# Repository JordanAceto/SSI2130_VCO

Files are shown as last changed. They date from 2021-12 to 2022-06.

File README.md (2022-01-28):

# SSI2130 based VCO PCB

## Features:
- Sine, Triangle, Sawtooth, and variable Pulse waves simultaneously available.
- All waveforms +/- 5vpp.
- Three 1 volt/octave inputs
- Through-zero linear FM
- Sync (choose hard or soft)
- PWM modulation inputs (choose triangle or saw input for the pulse wave)
- Designed to plug into a separate carrier pcb which houses the pots and jacks.

## [SCHEMATIC](https://github.com/JordanAceto/SSI2130_VCO/blob/main/construction_docs/SSI2130_VCO_schematic.pdf)

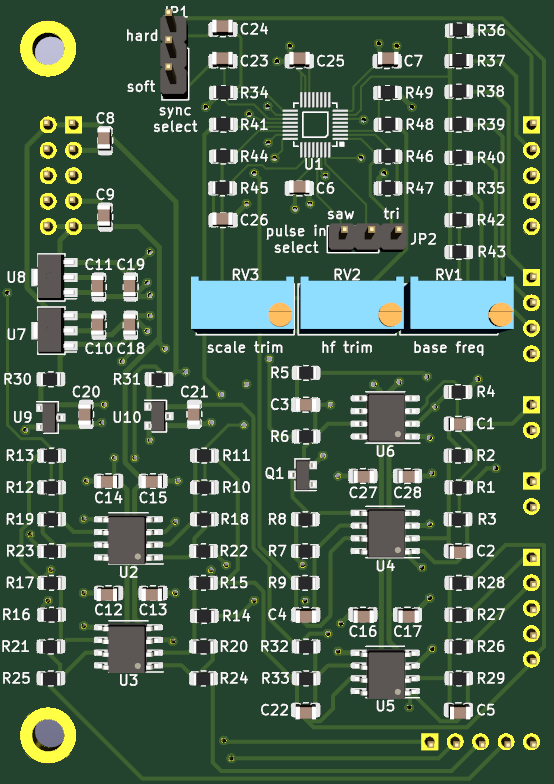
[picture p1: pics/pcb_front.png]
PCB front
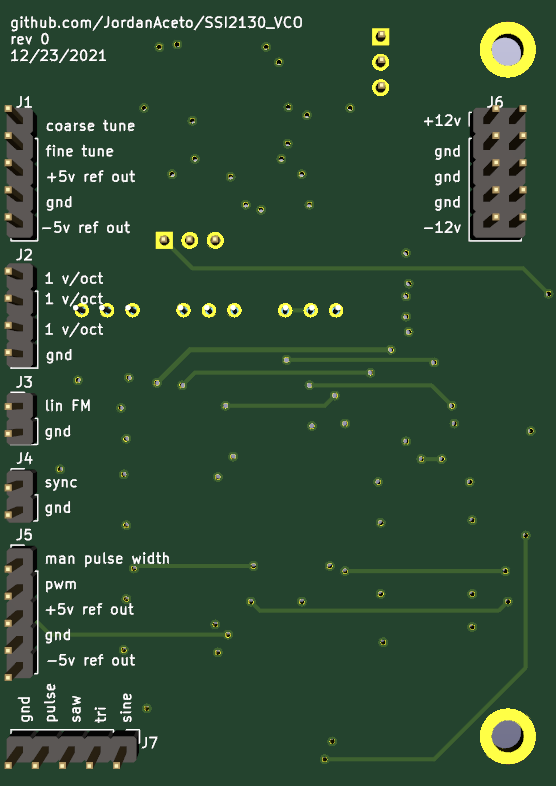
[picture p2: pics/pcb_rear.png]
PCB rear
  

| Power rail | Current consumption |
|---|---|
| +12v | 30mA |
| -12v | 30mA |

## Status of the project:

Task | Status |
---------|--------------|
Schematic capture | &#9745;
PCB layout | &#9745;
Test build | &#9745;
Safe to order boards| &#9745;

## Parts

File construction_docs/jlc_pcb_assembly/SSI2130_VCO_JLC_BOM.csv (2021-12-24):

Comment | Designator | Footprint | LCSC Part Number
100n | C1 C6 C7 C12 C13 C14 C15 C16 C17 C18 C19 C20 C21 C22 C27 C28 | 0805 | C49678
330n | C10 C11 | 0805 | C1740
20p | C2 | 0805 | C1798
10n | C23 C24 C26 | 0805 | C1710
100p | C3 C4 | 0805 | C1790
1n | C5 | 0805 | C46653
10u | C8 C9 C29 | 0805 | C440198
2N7002 | Q1 | SOT-23-3 | C8545
49k9 | R10 R12 R14 R16 | 0805 | C17719
1k | R22 R23 R24 R25 | 0805 | C17513
220k | R26 R27 | 0805 | C17556
200k | R13 R15 R17 R19 R20 R21 R28 | 0805 | C17539
51k | R29 | 0805 | C17737
100k | R1 R2 R3 R5 R18 R35 R36 | 0805 | C17407
1k8 | R30 | 0805 | C17398
1M | R37 | 0805 | C17514
100R | R4 | 0805 | C17408
470k | R41 | 0805 | C17709
270k | R43 | 0805 | C17589
47k | R44 | 0805 | C17713
270R | R45 | 0805 | C17590
3k9 | R46 | 0805 | C17614
4k7 | R31 R47 R49 | 0805 | C17673
12k | R48 | 0805 | C17444
10k | R6 R32 R33 R34 R42 R50 | 0805 | C17414
20k | R7 R8 R9 | 0805 | C4328
TL072 | U2 U3 U4 U5 | SOIC-8_3.9x4.9x1.27p | C6961
1N4048W | D1 D2 | SOD-123 | C81598

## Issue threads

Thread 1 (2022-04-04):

What's the finished product like?

pixiemars, 2022-04-04:
I am curious about the finished product. Have you got any demos anywhere?

JordanAceto, 2022-04-04:
Hello :)

It's about what you'd expect if you're familiar with the SSI2130. It is very close to the datasheet circuit, although I did use a few standard resistor values instead of the oddball values in the datasheet. See the sine shaper in particular. You could easily use the values straight from the datasheet if desired.

I've done one test build, and all seems to work well. Waveforms are the right amplitude and such, and the tuning seems very stable, sync work as expected, etc. I have not done any major testing though, just fired it up, tweaked the trimmers, and played it for a bit.

One thing I will change eventually is the range of the base frequency trimmer. With the current values it operates over a range that is too big. If you want to mess with this change r42 to something much bigger, like 100k and see how you like it.

There are not any demos, and I won't get to making any anytime soon. It's a pretty "boring" VCO for most part, with the addition of TZFM which does sound nice from my quick tests.

Overall, the intention of this board was a cheap and cheerful rendition of the SSI2130 that also plugs directly into other VCO motherboards that I have. It also works as an SSI2130 breakout board. I'm pretty happy with it, but it's more of an experimenters board than a full fledged product.

pixiemars, 2022-04-05:
Thanks for a detailed response.

I expected it to be a fairly vanilla implementation of the chip but I guess that's kind of what I am looking for, especially the TZFM part as I am a bit of a squelch monster.

I didn't realise that you had a one size fits all carrier board as well. That's a great idea.

I think I might have a crack at this once I have made some decent headway with the daisy patch submodule carrier board I have coming from jlpcb. I have a few digital module idea's I want to implement in the studio. Its also my first go at design and manufacture coming from a developer background.

Thanks for the info, awesome work as well btw.

JordanAceto, 2022-04-06:
Cool, let me know if you do get into it and have any questions or anything. The documentation and file structure is set up for my own way of organizing things.

I also see that it is still a KiCad 5 project. I've been slowly migrating projects to KiCad 6, and I'll eventually do that here. It should be pretty painless. But it's not necessary to fire up KiCad if you just want to build one.

There are gerbers and files for low cost smd assembly at JLCPCB. Not all of the parts are included in the assembly docs. Besides the SSI2130 itself a handful of other parts need to be hand soldered, like the voltage regulators, comparator, a few resistors, etc.

The daisy patch submodule carrier board sounds very cool! I eventually want to mess around with the daisy ecosystem.

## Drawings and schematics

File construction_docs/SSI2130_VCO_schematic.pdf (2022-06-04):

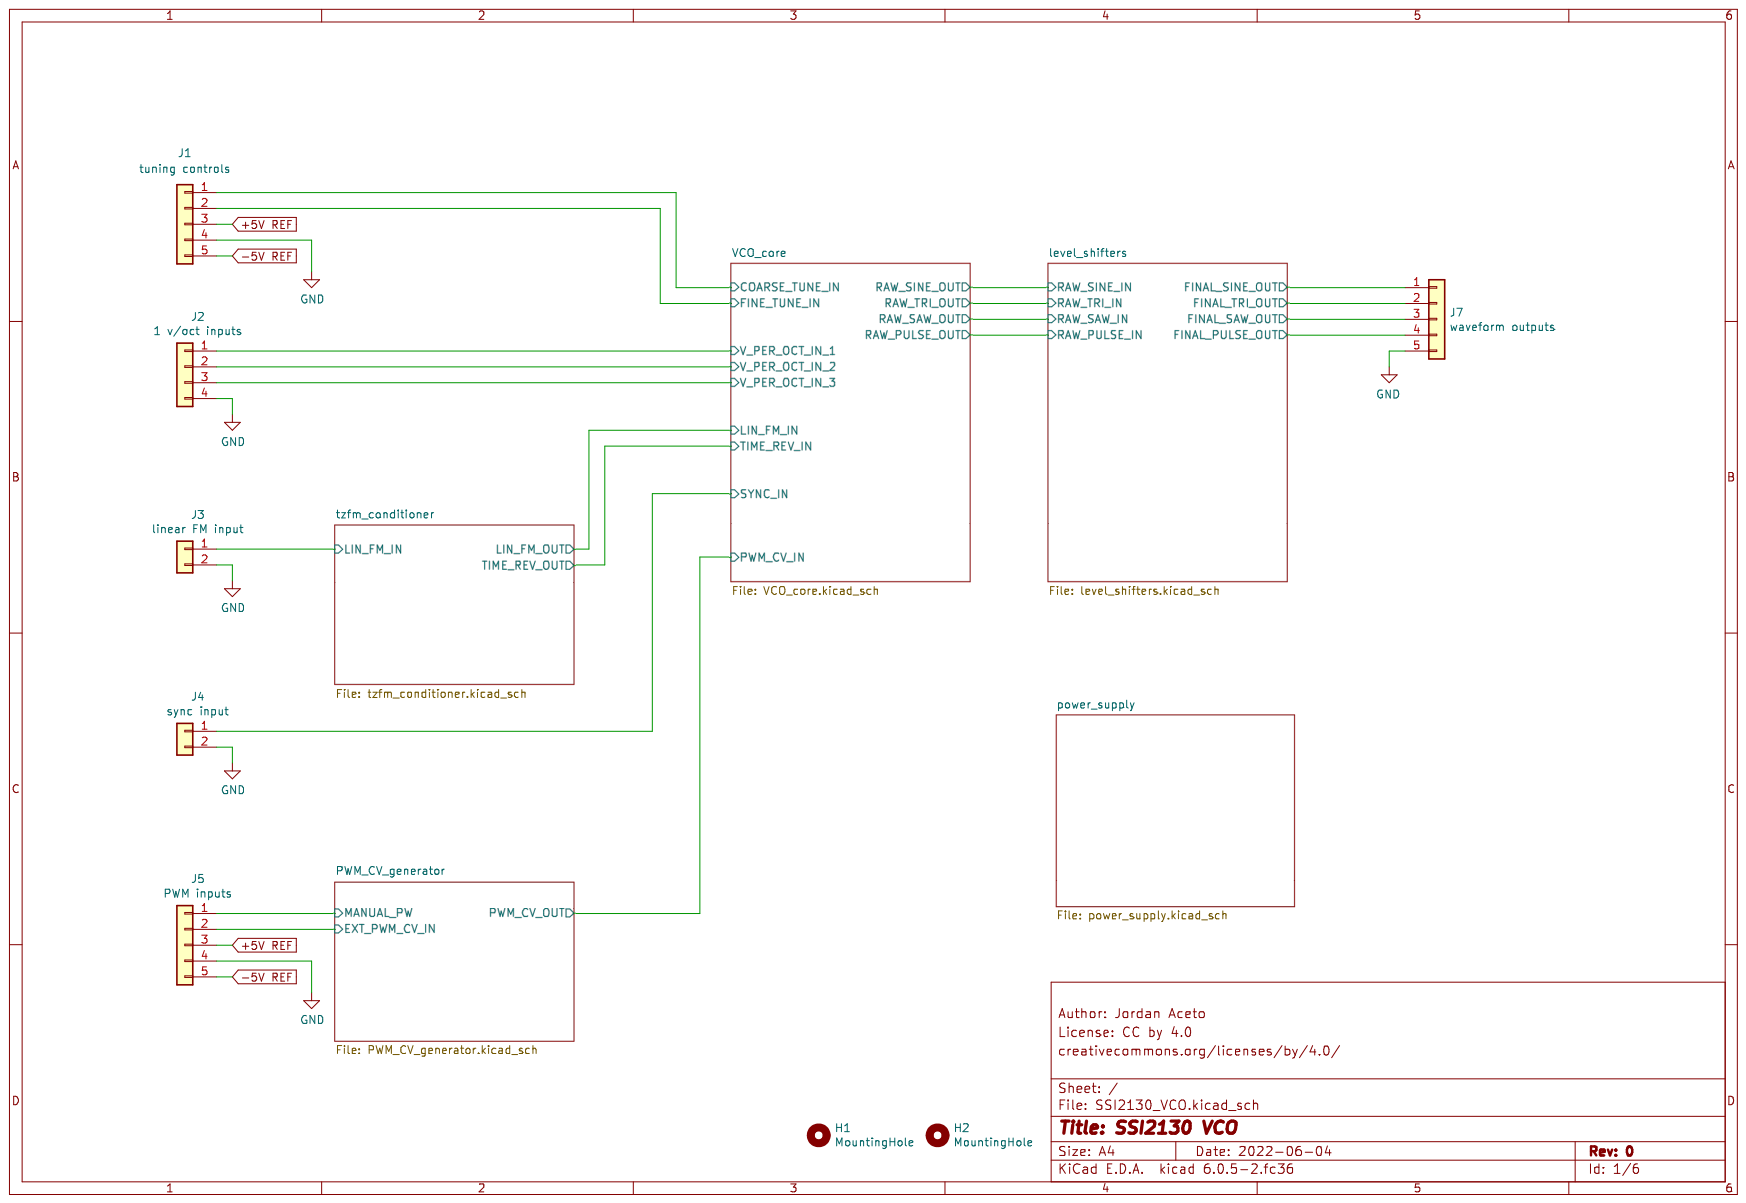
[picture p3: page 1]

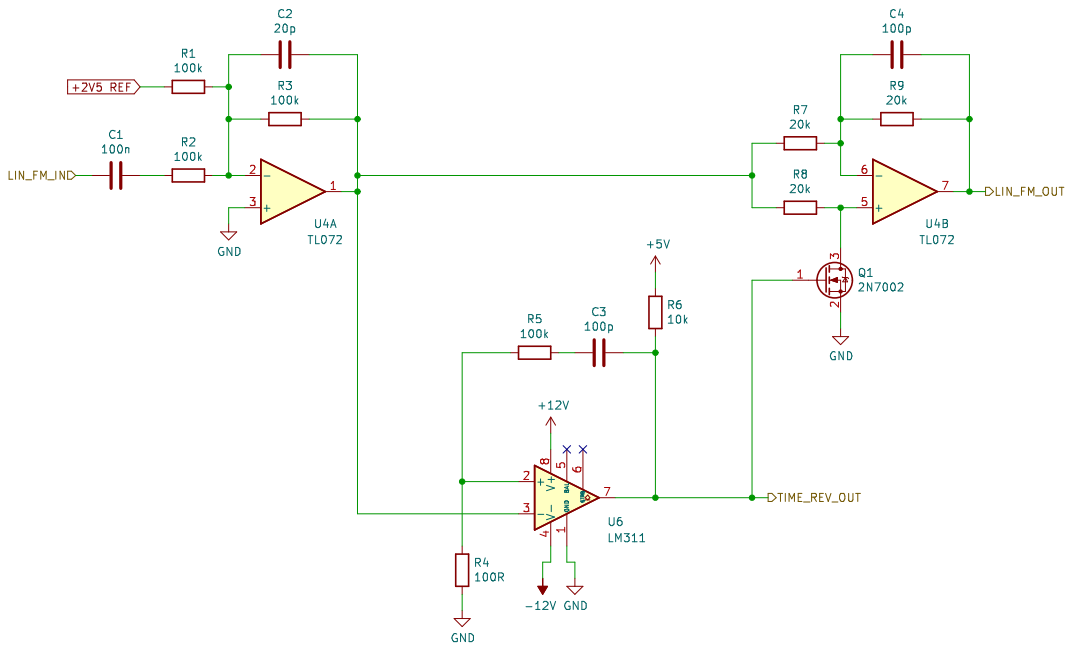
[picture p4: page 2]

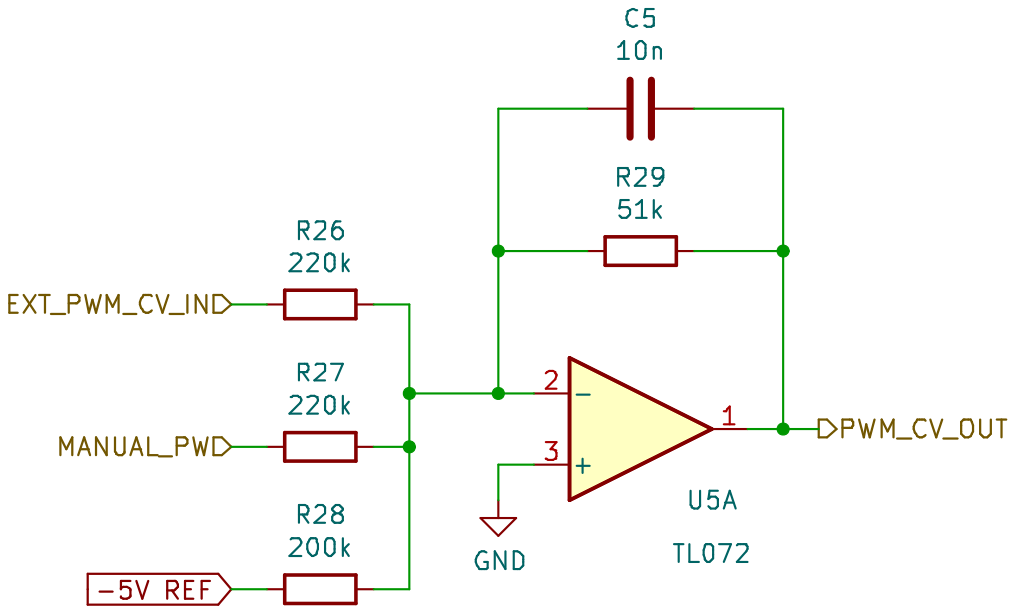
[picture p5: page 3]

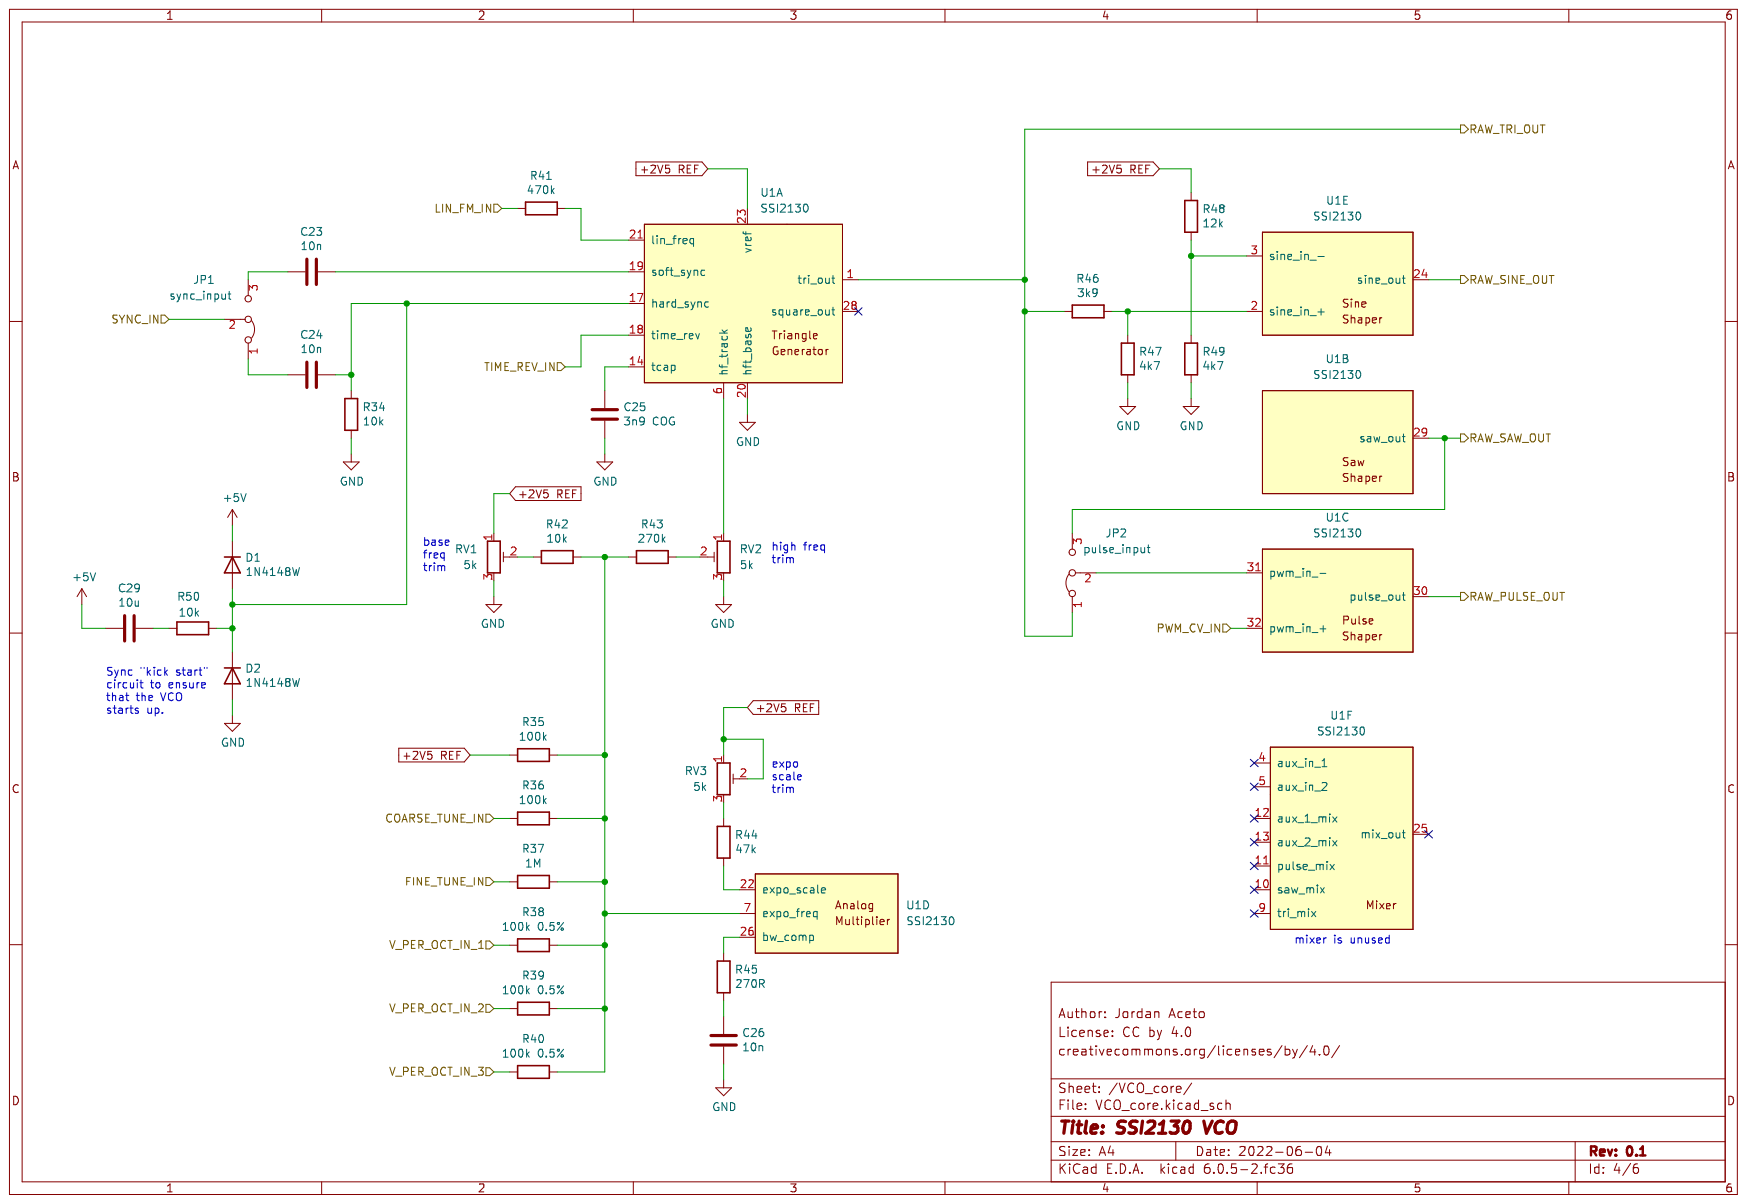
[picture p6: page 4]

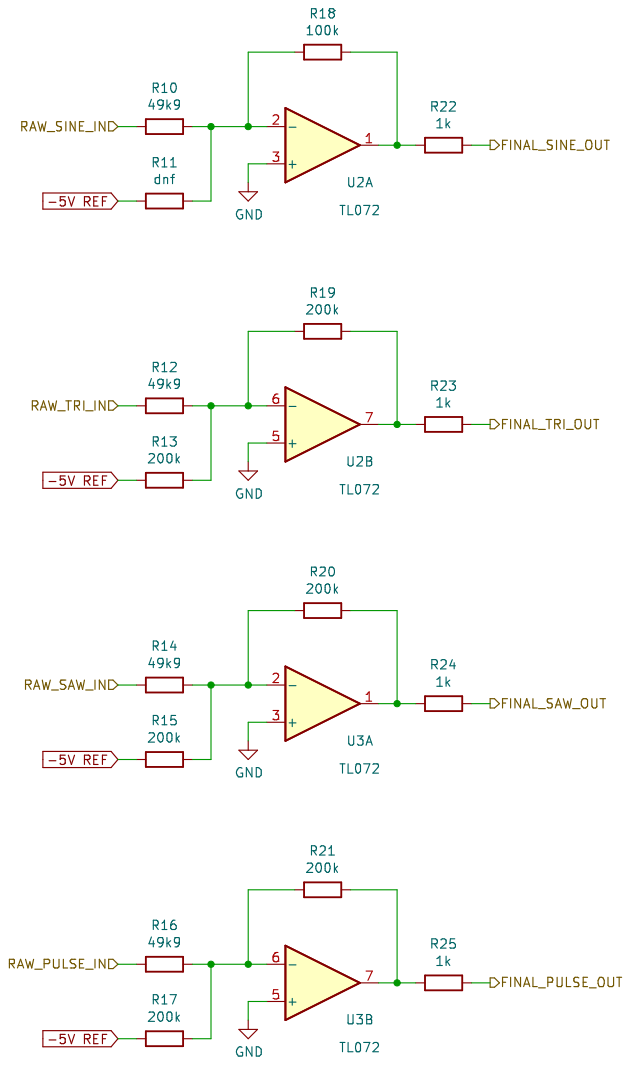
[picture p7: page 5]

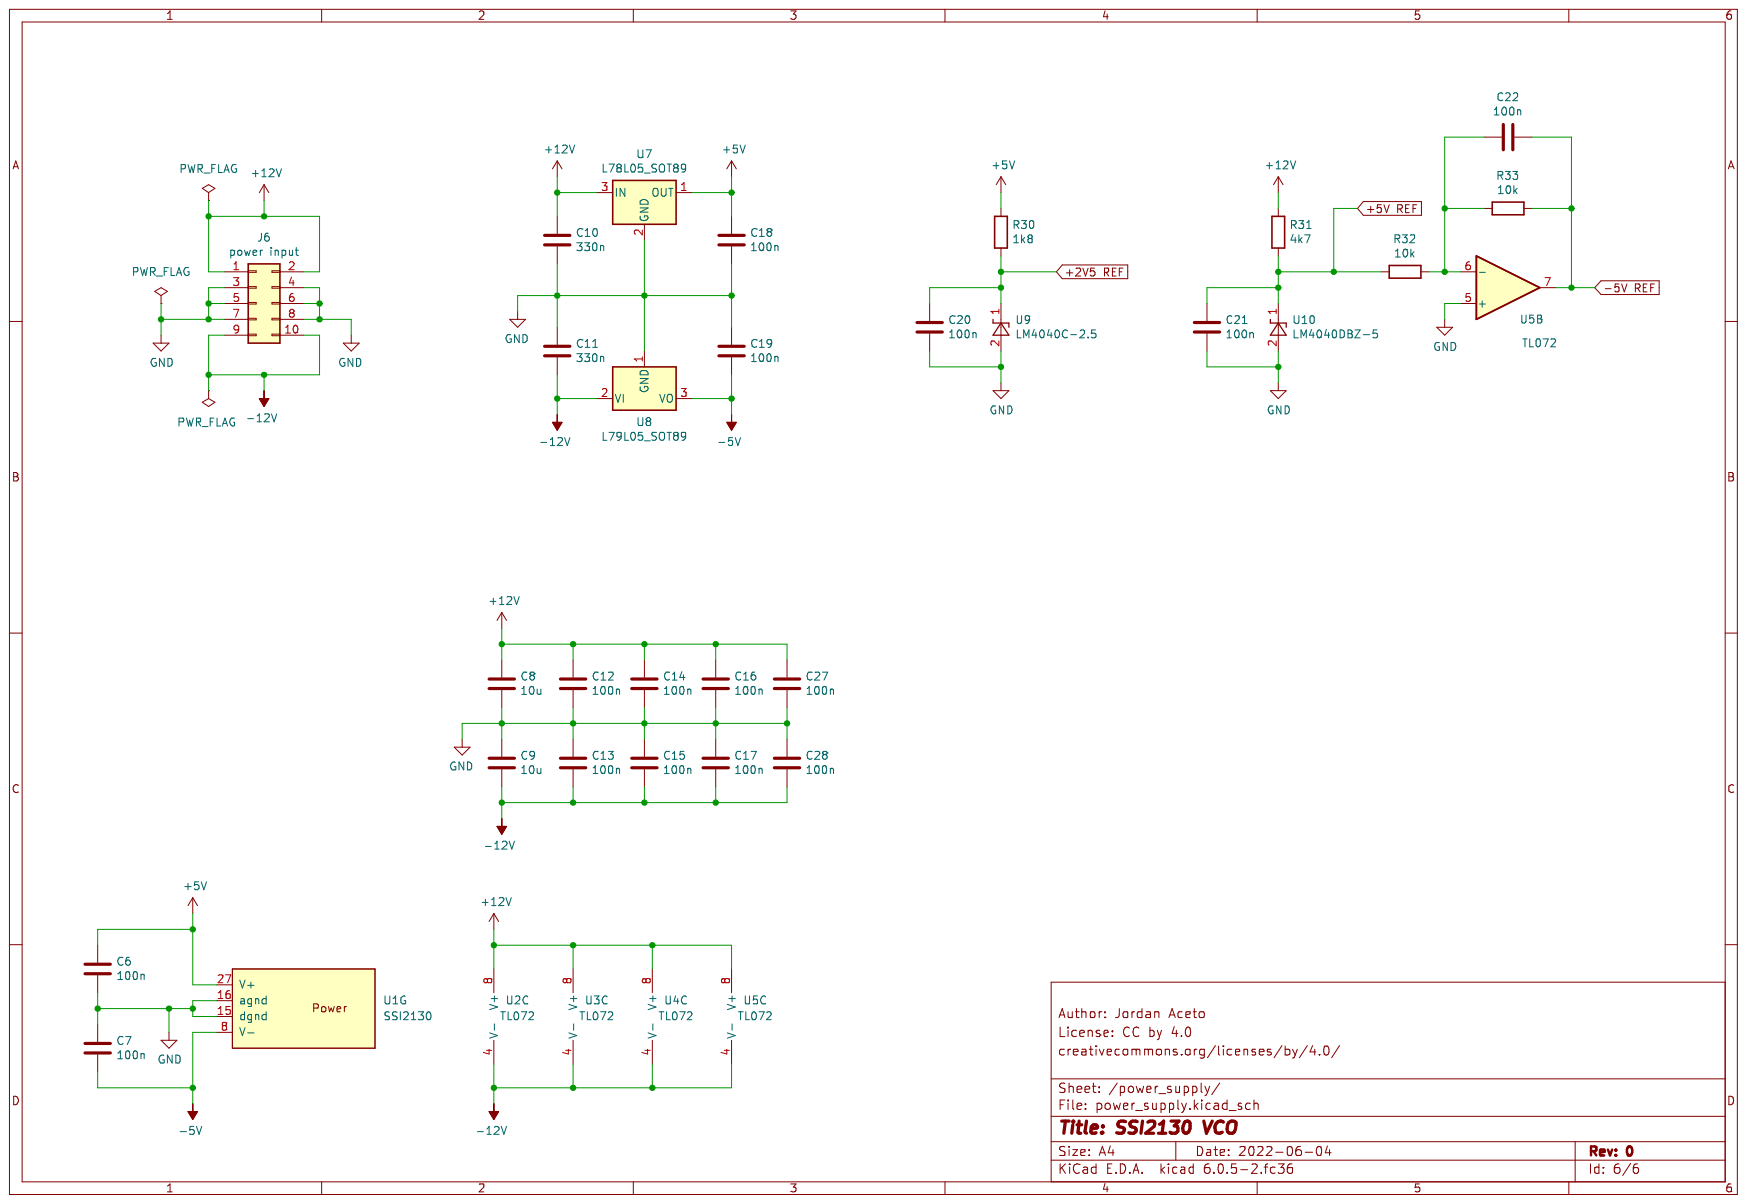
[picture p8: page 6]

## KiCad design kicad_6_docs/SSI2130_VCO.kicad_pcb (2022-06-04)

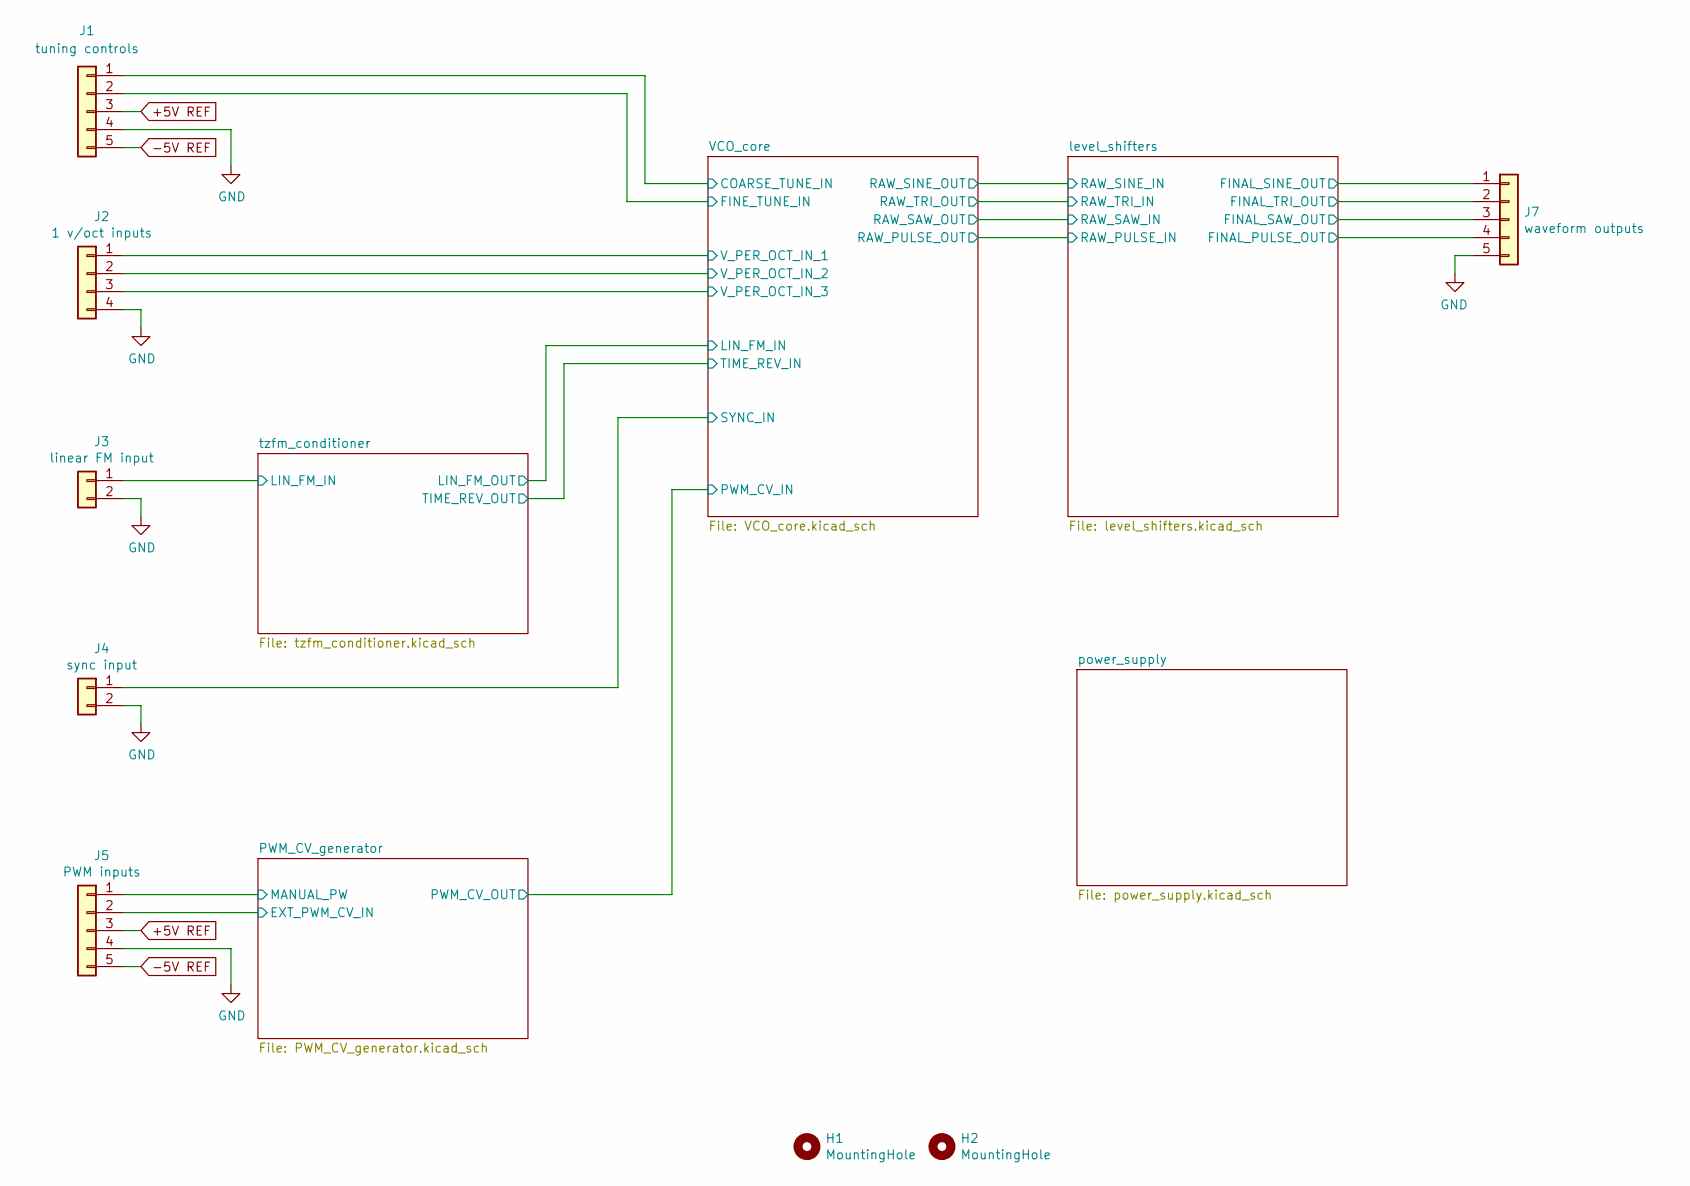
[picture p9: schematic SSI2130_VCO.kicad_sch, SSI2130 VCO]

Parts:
H1, H2: MountingHole; MountingHole_3.2mm_M3_DIN965_Pad
J1: tuning controls; PinHeader_1x05_P2.54mm_Vertical
J2: 1 v/oct inputs; PinHeader_1x04_P2.54mm_Vertical
J3: linear FM input; PinHeader_1x02_P2.54mm_Vertical
J4: sync input; PinHeader_1x02_P2.54mm_Vertical
J5: PWM inputs; PinHeader_1x05_P2.54mm_Vertical
J7: waveform outputs; PinHeader_1x05_P2.54mm_Vertical

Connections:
+5V REF: J1.3, J5.3; also elsewhere on the board
-5V REF: J1.5, J5.5; also elsewhere on the board
/PWM_CV_generator/EXT_PWM_CV_IN: J5.2; also elsewhere on the board
/PWM_CV_generator/MANUAL_PW: J5.1; also elsewhere on the board
/VCO_core/COARSE_TUNE_IN: J1.1; also elsewhere on the board
/VCO_core/FINE_TUNE_IN: J1.2; also elsewhere on the board
/VCO_core/SYNC_IN: J4.1; also elsewhere on the board
/VCO_core/V_PER_OCT_IN_1: J2.1; also elsewhere on the board
/VCO_core/V_PER_OCT_IN_2: J2.2; also elsewhere on the board
/VCO_core/V_PER_OCT_IN_3: J2.3; also elsewhere on the board
/level_shifters/FINAL_PULSE_OUT: J7.4; also elsewhere on the board
/level_shifters/FINAL_SAW_OUT: J7.3; also elsewhere on the board
/level_shifters/FINAL_SINE_OUT: J7.1; also elsewhere on the board
/level_shifters/FINAL_TRI_OUT: J7.2; also elsewhere on the board
/tzfm_conditioner/LIN_FM_IN: J3.1; also elsewhere on the board
GND: J1.4, J2.4, J3.2, J4.2, J5.4, J7.5; also elsewhere on the board

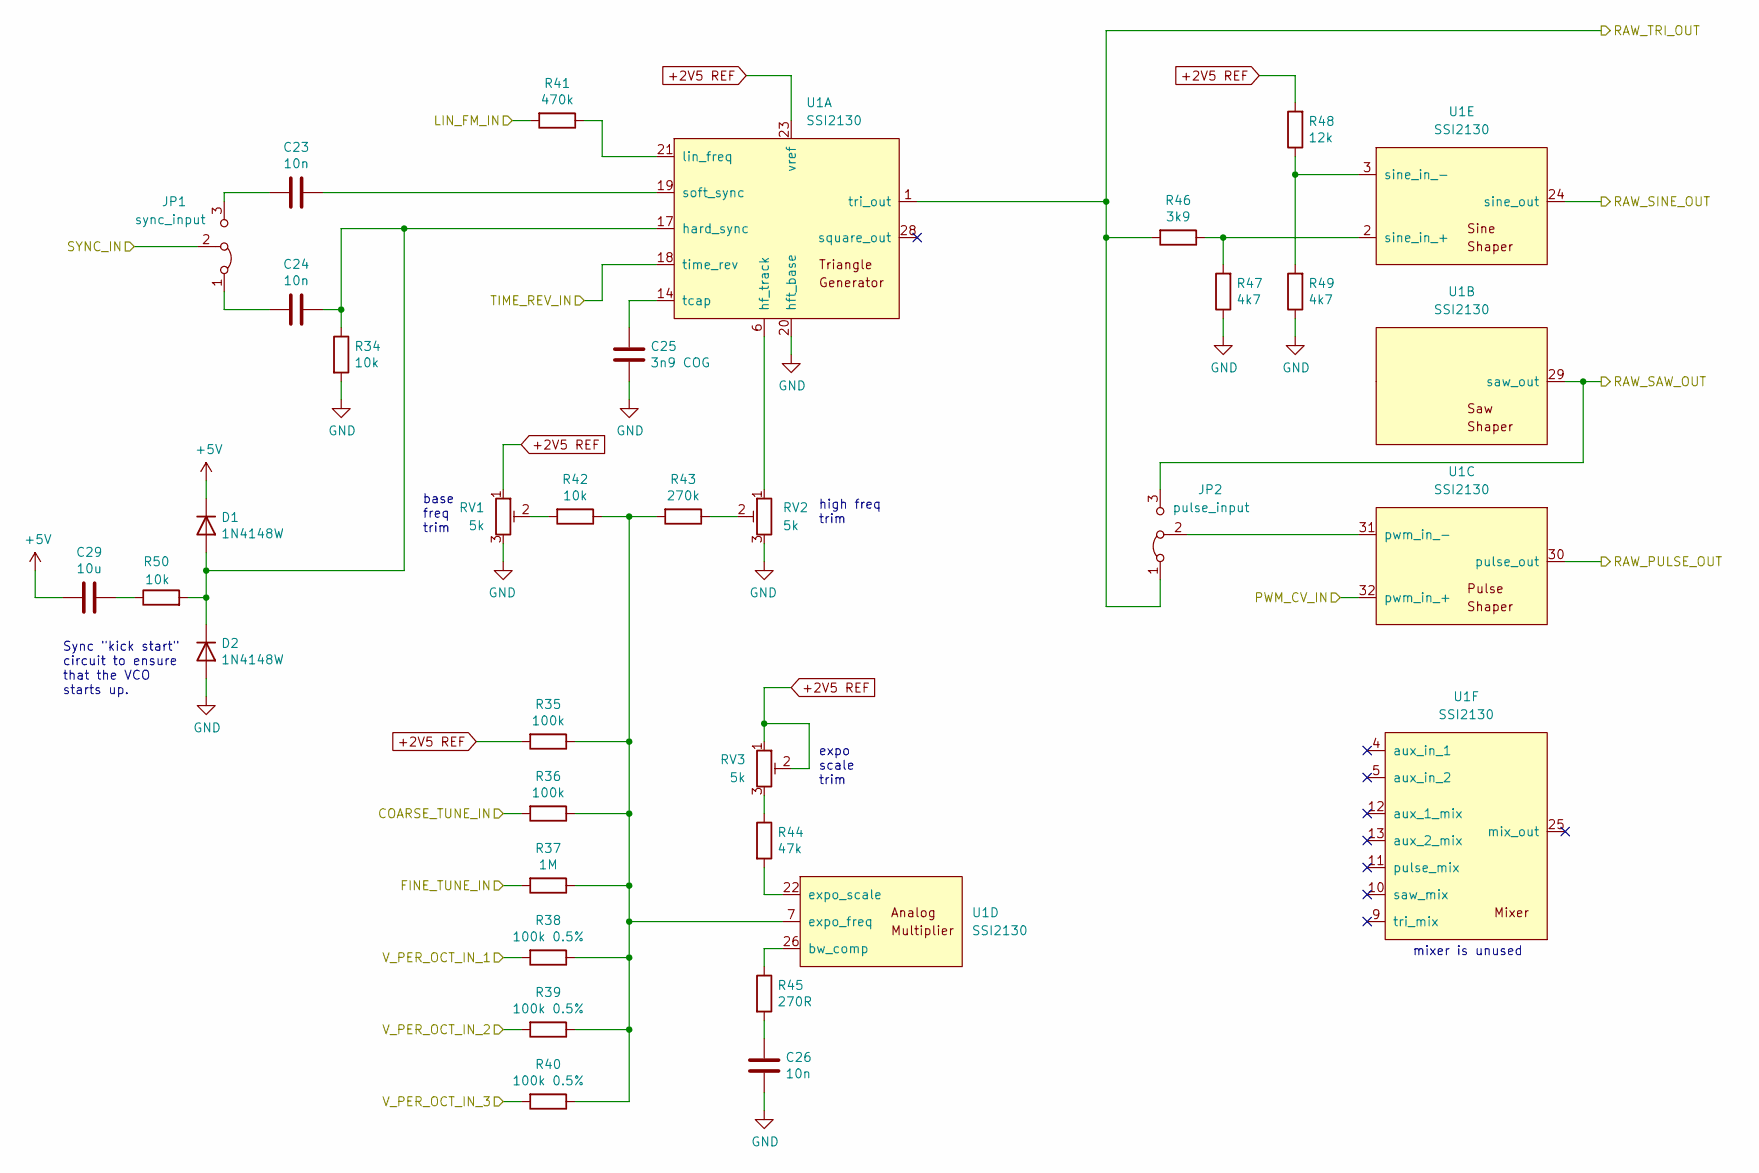
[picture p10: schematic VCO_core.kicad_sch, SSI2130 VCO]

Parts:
C23, C24, C26: 10n; C_0805_2012Metric
C25: 3n9 COG; C_0805_2012Metric
C29: 10u; C_0805_2012Metric
D1, D2: 1N4148W; D_SOD-123
JP1: sync_input; PinHeader_1x03_P2.54mm_Vertical
JP2: pulse_input; PinHeader_1x03_P2.54mm_Vertical
R34, R42, R50: 10k; R_0805_2012Metric
R35, R36: 100k; R_0805_2012Metric
R37: 1M; R_0805_2012Metric
R38, R39, R40: 100k 0.5%; R_0805_2012Metric
R41: 470k; R_0805_2012Metric
R43: 270k; R_0805_2012Metric
R44: 47k; R_0805_2012Metric
R45: 270R; R_0805_2012Metric
R46: 3k9; R_0805_2012Metric
R47, R49: 4k7; R_0805_2012Metric
R48: 12k; R_0805_2012Metric
RV1, RV2, RV3: 5k; Potentiometer_Bourns_3296W_Vertical
U1: SSI2130; PQN32_HandSoldering

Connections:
+2V5 REF: R35.2, R48.2, RV1.1, RV3.1, RV3.2, U1.23 (vref); also elsewhere on the board
+5V: C29.2, D1.1 (K); also elsewhere on the board
/PWM_CV_generator/PWM_CV_OUT: U1.32 (pwm_in_+); also elsewhere on the board
/VCO_core/COARSE_TUNE_IN: R36.2; also elsewhere on the board
/VCO_core/FINE_TUNE_IN: R37.2; also elsewhere on the board
/VCO_core/LIN_FM_IN: R41.2; also elsewhere on the board
/VCO_core/RAW_PULSE_OUT: U1.30 (pulse_out); also elsewhere on the board
/VCO_core/RAW_SAW_OUT: JP2.3 (B), U1.29 (saw_out); also elsewhere on the board
/VCO_core/RAW_SINE_OUT: U1.24 (sine_out); also elsewhere on the board
/VCO_core/RAW_TRI_OUT: JP2.1 (A), R46.2, U1.1 (tri_out); also elsewhere on the board
/VCO_core/SYNC_IN: JP1.2 (C); also elsewhere on the board
/VCO_core/TIME_REV_IN: U1.18 (time_rev); also elsewhere on the board
/VCO_core/V_PER_OCT_IN_1: R38.2; also elsewhere on the board
/VCO_core/V_PER_OCT_IN_2: R39.2; also elsewhere on the board
/VCO_core/V_PER_OCT_IN_3: R40.2; also elsewhere on the board
GND: C25.2, C26.2, D2.2 (A), R34.2, R47.1, R49.1, RV1.3, RV2.3, U1.20 (hft_base); also elsewhere on the board
unnamed: C23.1, U1.19 (soft_sync)
unnamed: C23.2, JP1.3 (B)
unnamed: C24.1, D1.2 (A), D2.1 (K), R34.1, R50.2, U1.17 (hard_sync)
unnamed: C24.2, JP1.1 (A)
unnamed: C25.1, U1.14 (tcap)
unnamed: C26.1, R45.2
unnamed: C29.1, R50.1
unnamed: JP2.2 (C), U1.31 (pwm_in_-)
unnamed: R35.1, R36.1, R37.1, R38.1, R39.1, R40.1, R42.1, R43.2, U1.7 (expo_freq)
unnamed: R41.1, U1.21 (lin_freq)
unnamed: R42.2, RV1.2
unnamed: R43.1, RV2.2
unnamed: R44.1, RV3.3
unnamed: R44.2, U1.22 (expo_scale)
unnamed: R45.1, U1.26 (bw_comp)
unnamed: R46.1, R47.2, U1.2 (sine_in_+)
unnamed: R48.1, R49.2, U1.3 (sine_in_-)
unnamed: RV2.1, U1.6 (hf_track)

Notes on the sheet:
base freq trim
mixer is unused
Sync "kick start" circuit to ensure that the VCO starts up.
expo scale trim
high freq trim

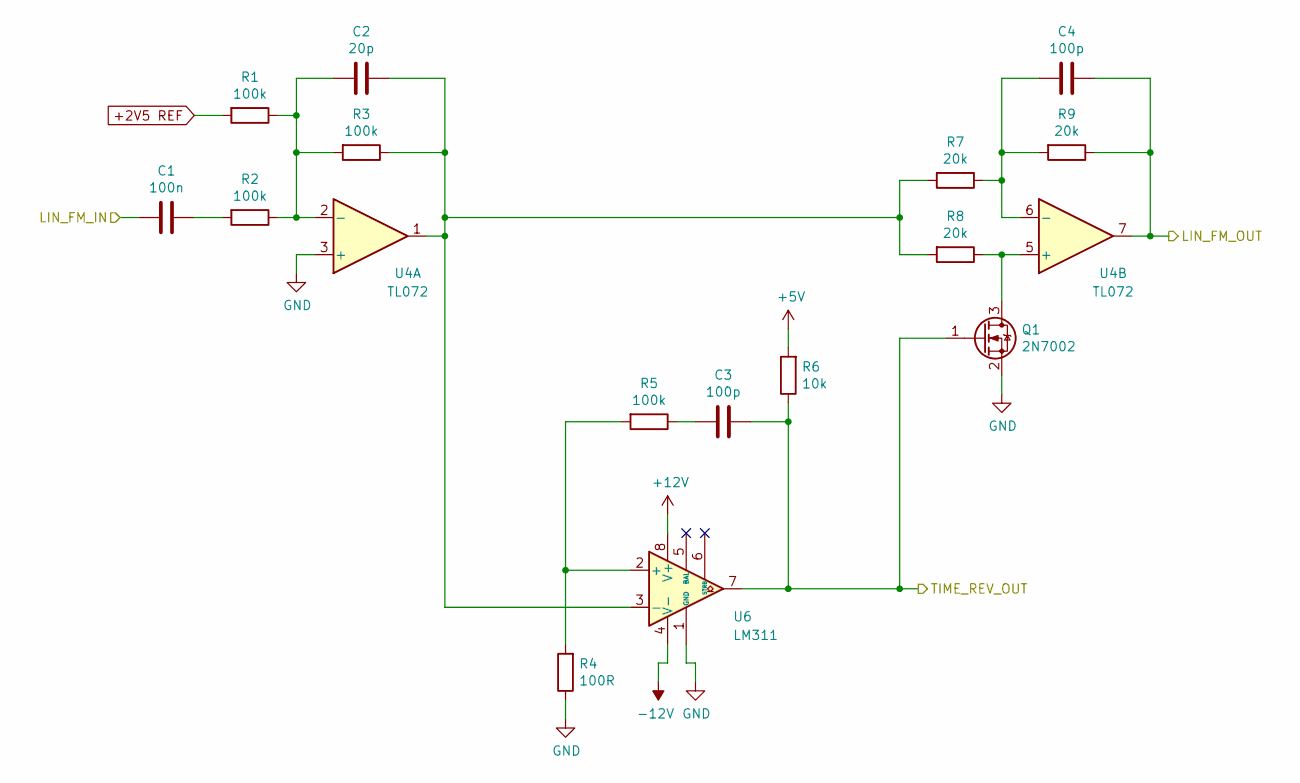
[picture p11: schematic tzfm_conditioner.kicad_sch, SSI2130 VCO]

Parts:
C1: 100n; C_0805_2012Metric
C2: 20p; C_0805_2012Metric
C3, C4: 100p; C_0805_2012Metric
Q1: 2N7002; SOT-23
R1, R2, R3, R5: 100k; R_0805_2012Metric
R4: 100R; R_0805_2012Metric
R6: 10k; R_0805_2012Metric
R7, R8, R9: 20k; R_0805_2012Metric
U4: TL072; SOIC-8_3.9x4.9mm_P1.27mm
U6: LM311; SOIC-8_3.9x4.9mm_P1.27mm

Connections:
+2V5 REF: R1.2; also elsewhere on the board
+5V: R6.2; also elsewhere on the board
+12V: U6.8 (V+); also elsewhere on the board
-12V: U6.4 (V-); also elsewhere on the board
/VCO_core/LIN_FM_IN: C4.1, R9.1, U4.7; also elsewhere on the board
/VCO_core/TIME_REV_IN: C3.1, Q1.1 (G), R6.1, U6.7; also elsewhere on the board
/tzfm_conditioner/LIN_FM_IN: C1.2; also elsewhere on the board
GND: Q1.2 (S), R4.1, U4.3 (+), U6.1 (GND); also elsewhere on the board
unnamed: C1.1, R2.2
unnamed: C2.1, R3.1, R7.2, R8.2, U4.1, U6.3 (-)
unnamed: C2.2, R1.1, R2.1, R3.2, U4.2 (-)
unnamed: C3.2, R5.1
unnamed: C4.2, R7.1, R9.2, U4.6 (-)
unnamed: Q1.3 (D), R8.1, U4.5 (+)
unnamed: R4.2, R5.2, U6.2 (+)

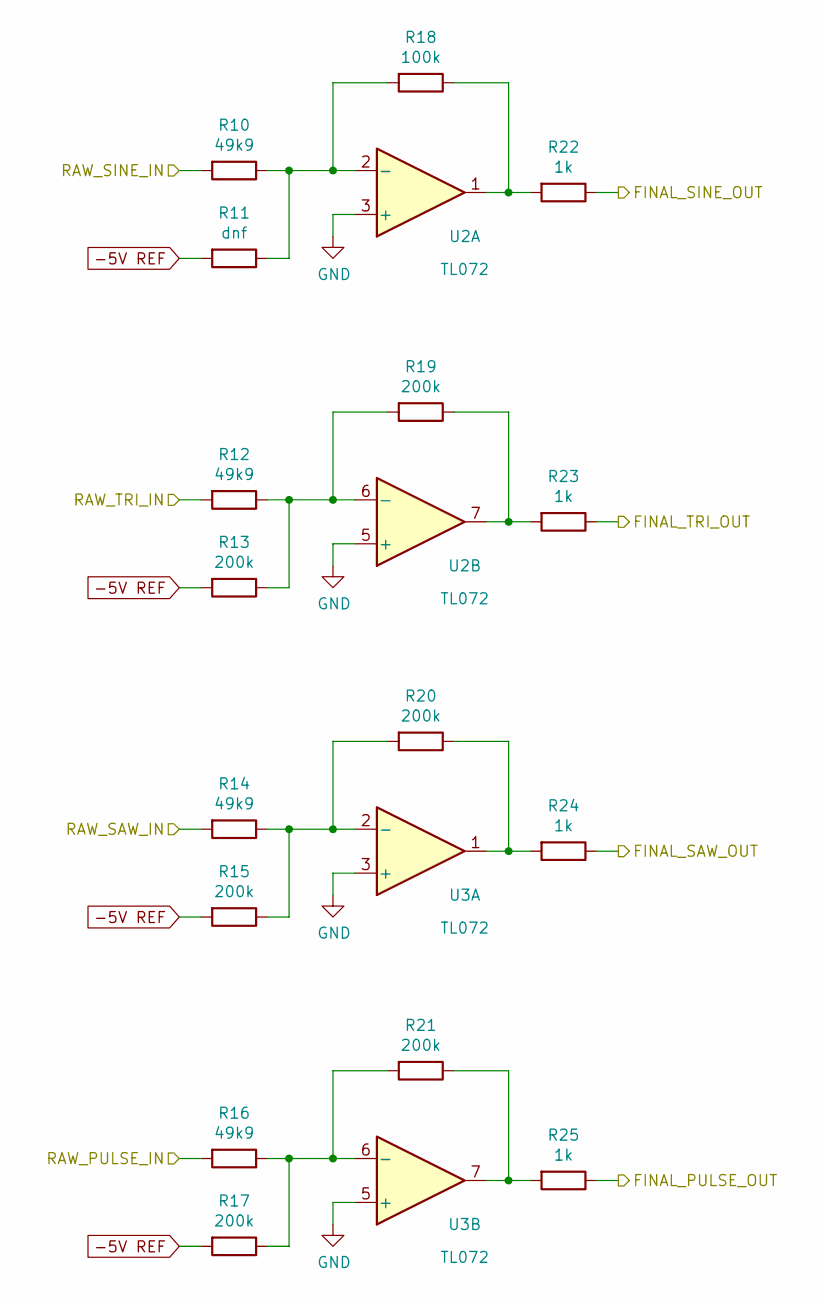
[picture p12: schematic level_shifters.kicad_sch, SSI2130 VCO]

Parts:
R10, R12, R14, R16: 49k9; R_0805_2012Metric
R11: dnf; R_0805_2012Metric
R13, R15, R17, R19, R20, R21: 200k; R_0805_2012Metric
R18: 100k; R_0805_2012Metric
R22, R23, R24, R25: 1k; R_0805_2012Metric
U2, U3: TL072; SOIC-8_3.9x4.9mm_P1.27mm

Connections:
-5V REF: R11.2, R13.2, R15.2, R17.2; also elsewhere on the board
/VCO_core/RAW_PULSE_OUT: R16.2; also elsewhere on the board
/VCO_core/RAW_SAW_OUT: R14.2; also elsewhere on the board
/VCO_core/RAW_SINE_OUT: R10.2; also elsewhere on the board
/VCO_core/RAW_TRI_OUT: R12.2; also elsewhere on the board
/level_shifters/FINAL_PULSE_OUT: R25.1; also elsewhere on the board
/level_shifters/FINAL_SAW_OUT: R24.1; also elsewhere on the board
/level_shifters/FINAL_SINE_OUT: R22.1; also elsewhere on the board
/level_shifters/FINAL_TRI_OUT: R23.1; also elsewhere on the board
GND: U2.3 (+), U2.5 (+), U3.3 (+), U3.5 (+); also elsewhere on the board
unnamed: R10.1, R11.1, R18.2, U2.2 (-)
unnamed: R12.1, R13.1, R19.2, U2.6 (-)
unnamed: R14.1, R15.1, R20.2, U3.2 (-)
unnamed: R16.1, R17.1, R21.2, U3.6 (-)
unnamed: R18.1, R22.2, U2.1
unnamed: R19.1, R23.2, U2.7
unnamed: R20.1, R24.2, U3.1
unnamed: R21.1, R25.2, U3.7

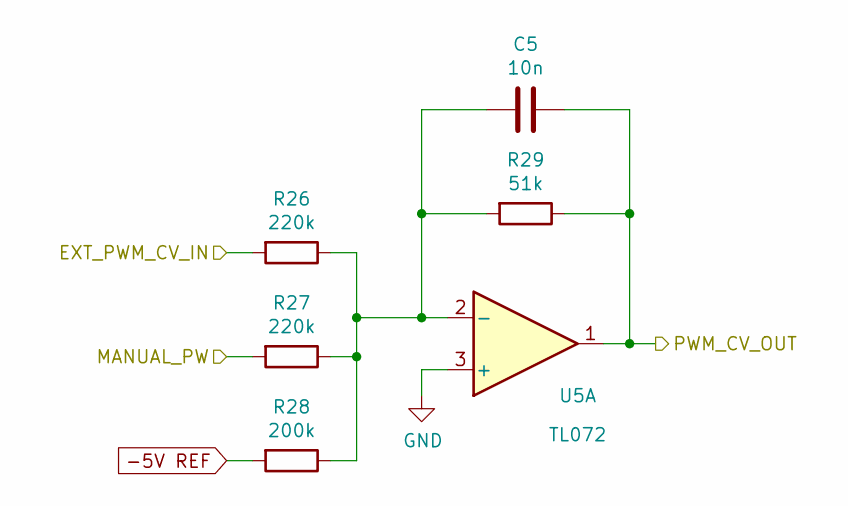
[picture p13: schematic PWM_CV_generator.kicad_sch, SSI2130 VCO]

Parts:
C5: 10n; C_0805_2012Metric
R26, R27: 220k; R_0805_2012Metric
R28: 200k; R_0805_2012Metric
R29: 51k; R_0805_2012Metric
U5: TL072; SOIC-8_3.9x4.9mm_P1.27mm

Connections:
-5V REF: R28.2; also elsewhere on the board
/PWM_CV_generator/EXT_PWM_CV_IN: R26.2; also elsewhere on the board
/PWM_CV_generator/MANUAL_PW: R27.2; also elsewhere on the board
/PWM_CV_generator/PWM_CV_OUT: C5.1, R29.1, U5.1; also elsewhere on the board
GND: U5.3 (+); also elsewhere on the board
unnamed: C5.2, R26.1, R27.1, R28.1, R29.2, U5.2 (-)

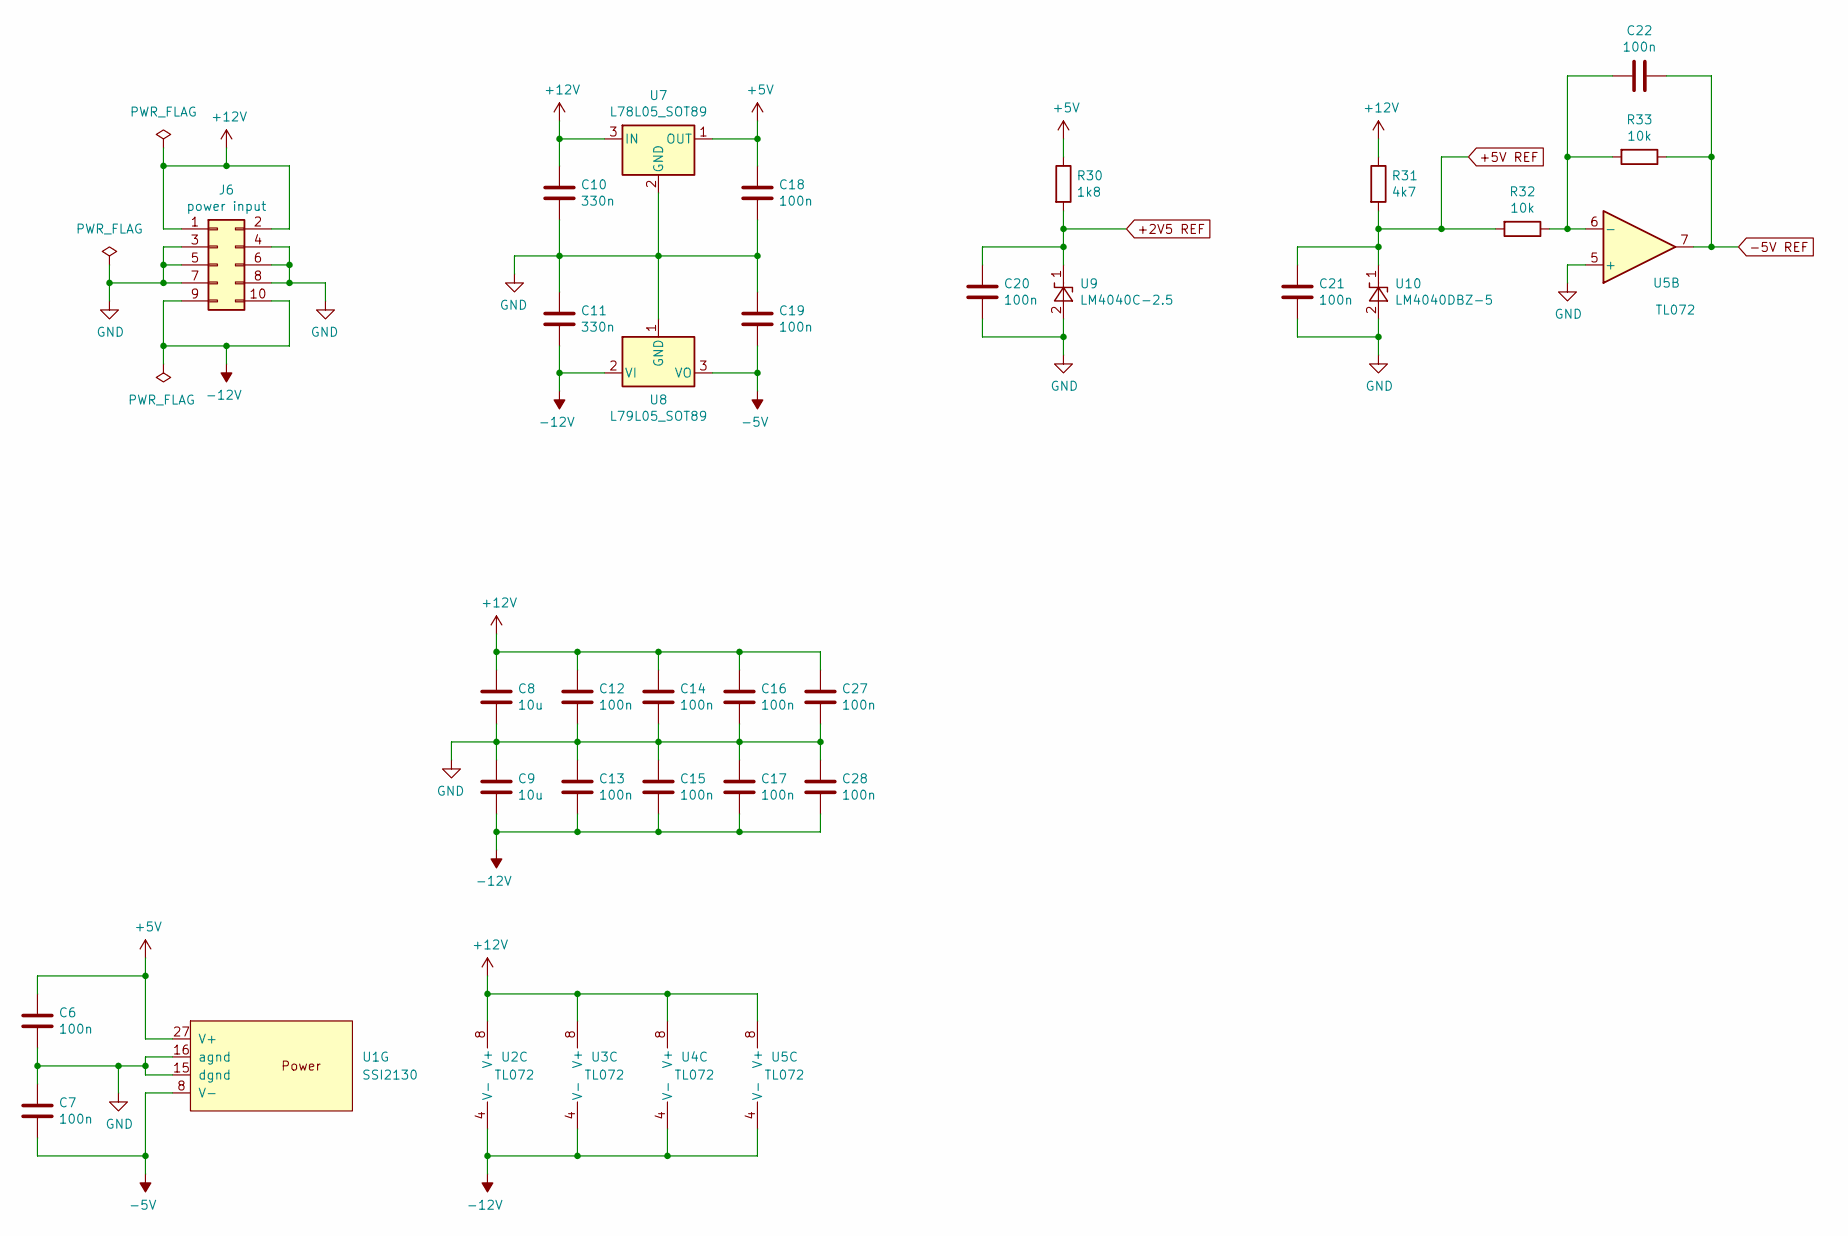
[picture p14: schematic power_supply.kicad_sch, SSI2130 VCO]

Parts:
C6, C7, C12, C13, C14, C15, C16, C17, C18, C19, C20, C21, C22, C27, C28: 100n; C_0805_2012Metric
C8, C9: 10u; C_0805_2012Metric
C10, C11: 330n; C_0805_2012Metric
J6: power input; PinHeader_2x05_P2.54mm_Vertical
R30: 1k8; R_0805_2012Metric
R31: 4k7; R_0805_2012Metric
R32, R33: 10k; R_0805_2012Metric
U1: SSI2130; PQN32_HandSoldering
U2, U3, U4, U5: TL072; SOIC-8_3.9x4.9mm_P1.27mm
U7: L78L05_SOT89; SOT-89-3
U8: L79L05_SOT89; SOT-89-3
U9: LM4040C-2.5; SOT-23
U10: LM4040DBZ-5; SOT-23

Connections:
+2V5 REF: C20.1, R30.2, U9.1 (K); also elsewhere on the board
+5V: C6.1, C18.1, R30.1, U1.27 (V+), U7.1 (OUT); also elsewhere on the board
+5V REF: C21.1, R31.2, R32.2, U10.1 (K); also elsewhere on the board
+12V: C8.1, C10.1, C12.1, C14.1, C16.1, C27.1, J6.1, J6.2, R31.1, U2.8 (V+), U3.8 (V+), U4.8 (V+), U5.8 (V+), U7.3 (IN); also elsewhere on the board
-5V: C7.2, C19.2, U1.8 (V-), U8.3 (VO)
-5V REF: C22.1, R33.1, U5.7; also elsewhere on the board
-12V: C9.2, C11.2, C13.2, C15.2, C17.2, C28.2, J6.9, J6.10, U2.4 (V-), U3.4 (V-), U4.4 (V-), U5.4 (V-), U8.2 (VI); also elsewhere on the board
GND: C6.2, C7.1, C8.2, C9.1, C10.2, C11.1, C12.2, C13.1, C14.2, C15.1, C16.2, C17.1, C18.2, C19.1, C20.2, C21.2, C27.2, C28.1, J6.3, J6.4, J6.5, J6.6, J6.7, J6.8, U1.15 (dgnd), U1.16 (agnd), U5.5 (+), U7.2 (GND), U8.1 (GND), U9.2 (A), U10.2 (A); also elsewhere on the board
unnamed: C22.2, R32.1, R33.2, U5.6 (-)

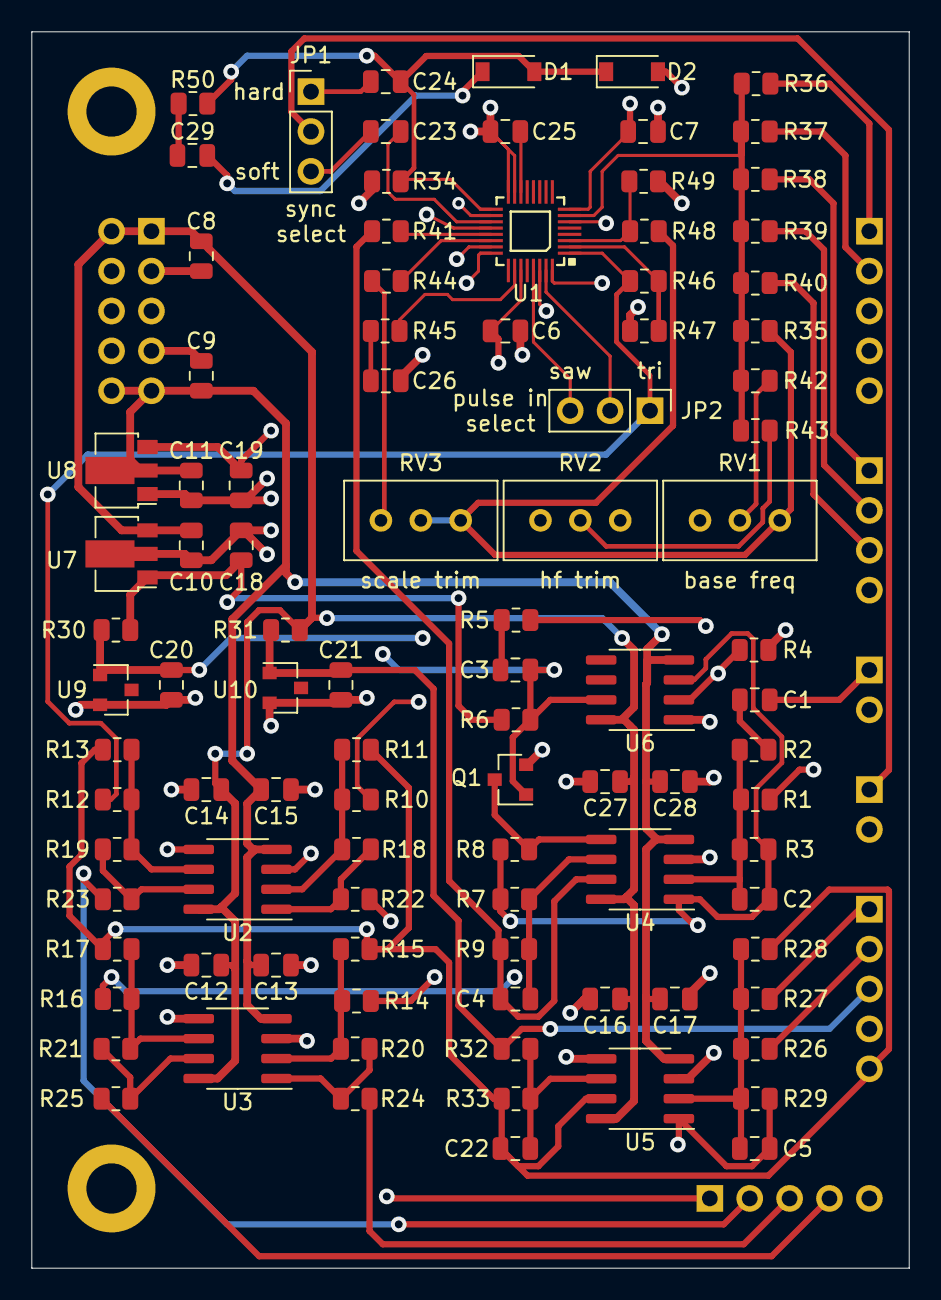
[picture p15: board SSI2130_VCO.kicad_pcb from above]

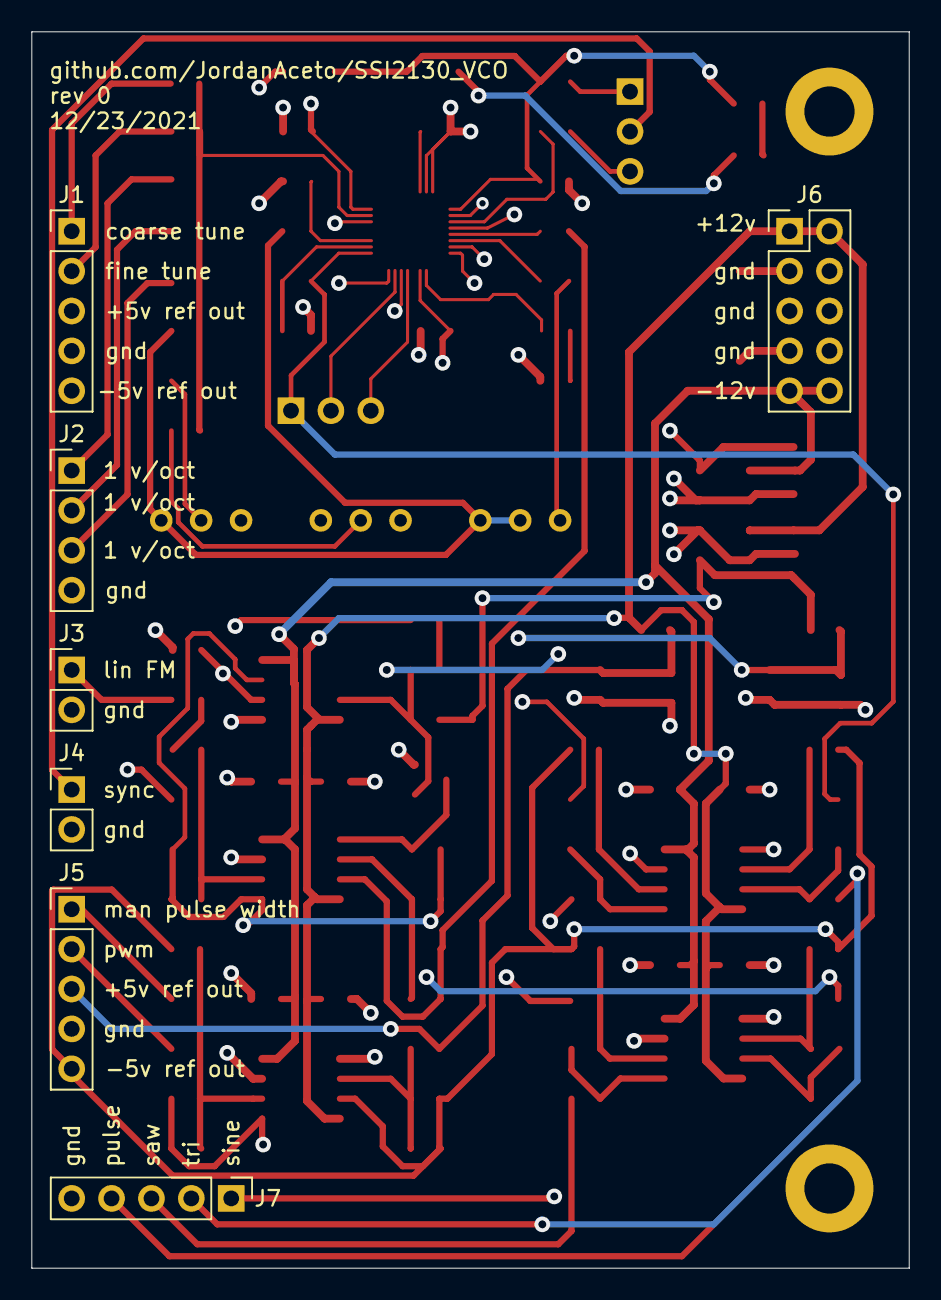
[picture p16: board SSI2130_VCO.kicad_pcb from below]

Board: 4 copper layers, 55.9 x 78.7 mm, 106 parts (7 on the bottom side), 63 nets.

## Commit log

2021-12-23 fix schematic link
2021-12-23 reduce amt of weird resistor vals
    [PWM_CV_generator.sch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]
2021-12-23 fix error where wires were crossed
    [SSI2130_VCO-B_Mask.gbs, SSI2130_VCO-B_Paste.gbp, SSI2130_VCO-B_SilkS.gbo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]
2021-12-24 add kick-start network to ensure start up
    [SSI2130_VCO-B_Mask.gbs, SSI2130_VCO-B_Paste.gbp, SSI2130_VCO-B_SilkS.gbo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]
2022-06-04 Update to KiCad 6, tweak SSI2130 symbol
    [PWM_CV_generator.kicad_sch, PWM_CV_generator.sch, SSI2130_VCO.kicad_pcb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]

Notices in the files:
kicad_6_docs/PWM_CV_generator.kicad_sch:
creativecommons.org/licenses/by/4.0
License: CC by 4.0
